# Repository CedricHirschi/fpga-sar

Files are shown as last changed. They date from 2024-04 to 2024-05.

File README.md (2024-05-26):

# FPGA-SAR

Material for the SAR ADC project in the **iCEBreaker FPGA For IoT Sensing Systems** FS2024 course.

## Project Description

Build a SAR ADC and a way to read its values.
- [x] Build analog part (See [hardware/](hardware/))
- [x] Develop SAR core (See [verilog/](verilog/))
- [x] Develop UART readout core (See [verilog/](verilog/))
- [ ] Optional: Evaluate speed and accuracy

## Project Structure

- [hardware/](hardware/): Contains the KiCad project for the analog part of the SAR ADC
- [verilog/](verilog/): Contains the Verilog code for the SAR ADC and UART readout core
- [gui.ipynb](gui.ipynb): Jupyter notebook for plotting the ADC values
- [activate.sh](activate.sh): Script to activate the virtual environment for development with APIO and Jupyter Notebook
- [presentation.pptx](presentation.pptx): Presentation slides for the project

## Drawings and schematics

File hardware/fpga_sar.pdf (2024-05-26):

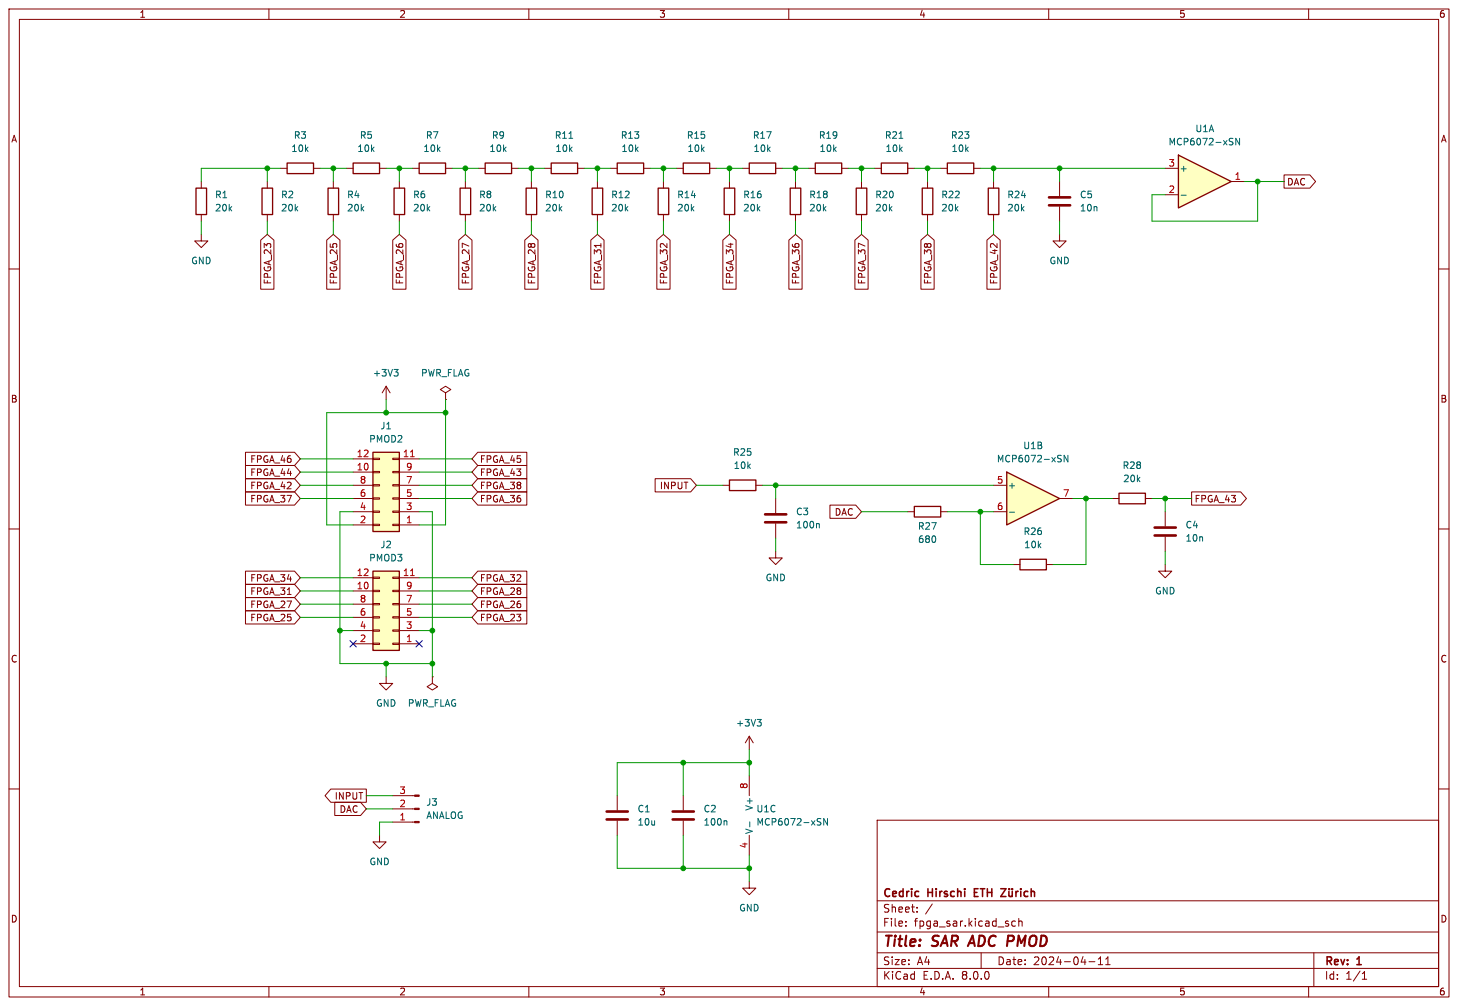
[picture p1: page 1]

Id: 1/1 Title: SAR ADC PMOD

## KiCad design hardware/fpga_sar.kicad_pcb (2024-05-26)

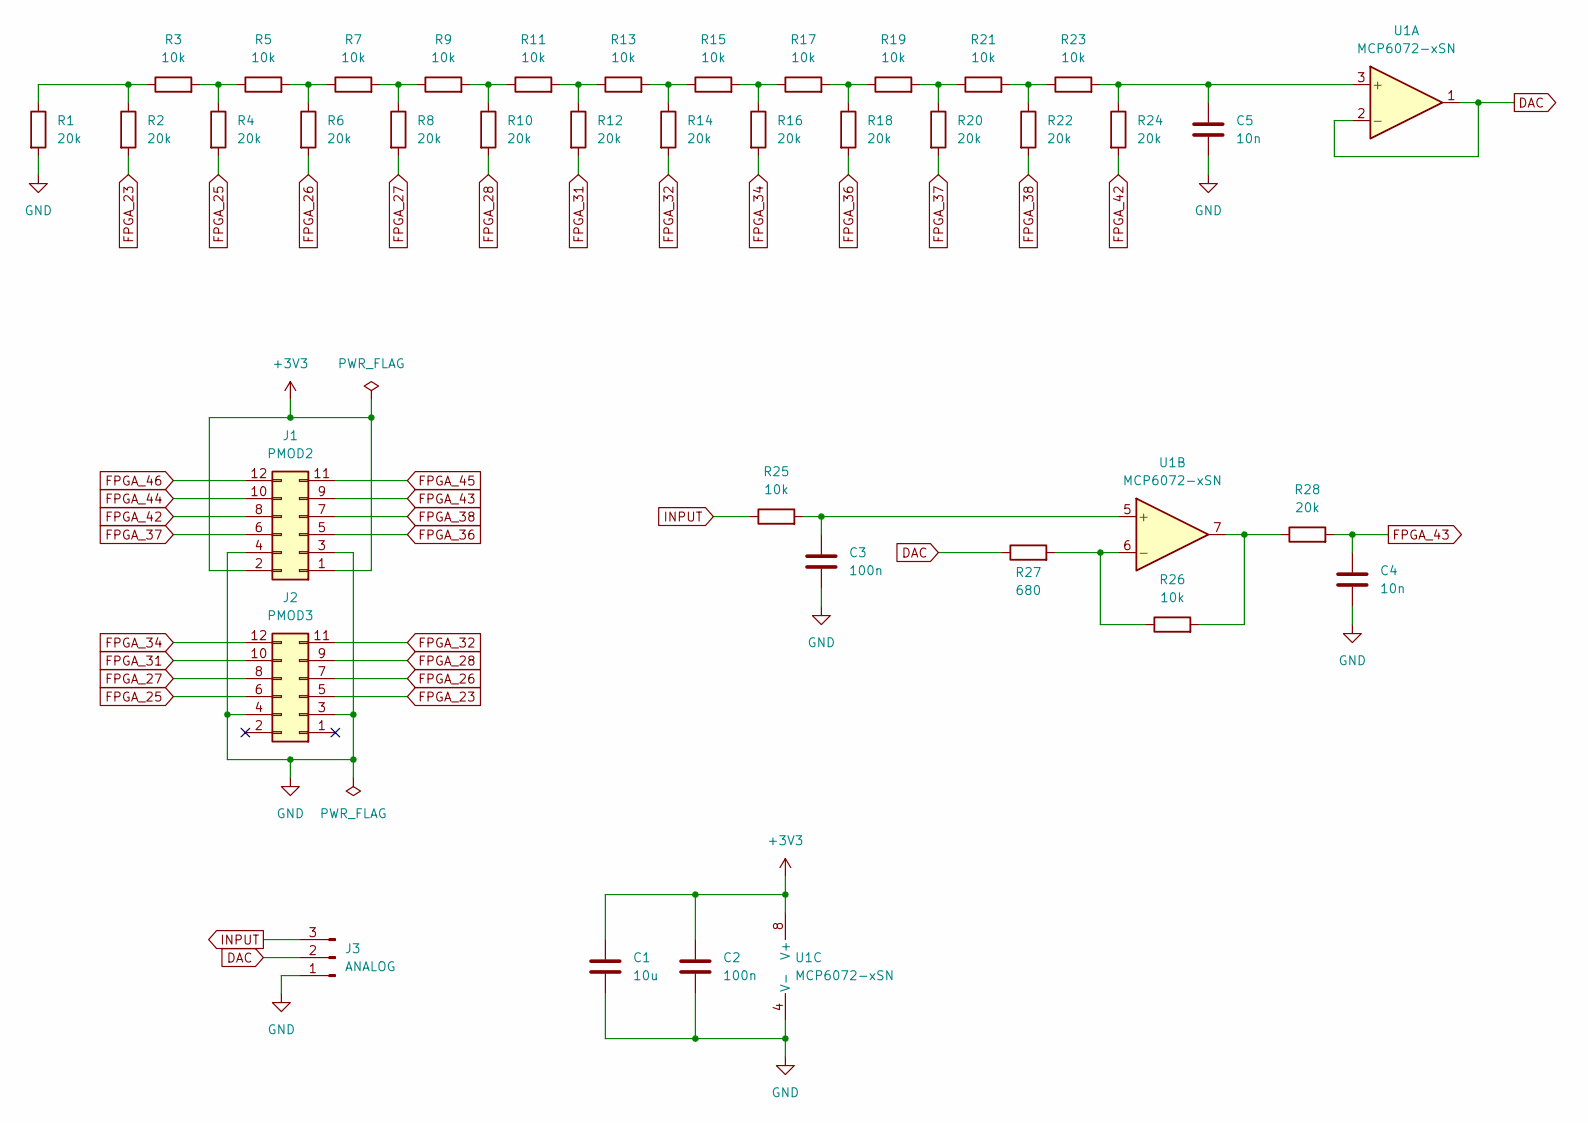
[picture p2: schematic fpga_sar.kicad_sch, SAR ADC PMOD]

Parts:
C1: 10u; C_0402_1005Metric
C2, C3: 100n; C_0402_1005Metric
C4, C5: 10n; C_0402_1005Metric
J1: PMOD2; PinHeader_2x06_P2.54mm_Horizontal
J2: PMOD3; PinHeader_2x06_P2.54mm_Horizontal
J3: ANALOG; PinHeader_1x03_P2.54mm_Vertical
R1, R2, R4, R6, R8, R10, R12, R14, R16, R18, R20, R22, R24, R28: 20k; R_0402_1005Metric
R3, R5, R7, R9, R11, R13, R15, R17, R19, R21, R23, R25, R26: 10k; R_0402_1005Metric
R27: 680; R_0402_1005Metric
U1: MCP6072-xSN; SOIC-8_3.9x4.9mm_P1.27mm

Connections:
+3V3: C1.1, C2.1, J1.1, J1.2, U1.8 (V+)
DAC: J3.2, R27.1, U1.1, U1.2 (-)
FPGA_23: J2.5, R2.2
FPGA_25: J2.6, R4.2
FPGA_26: J2.7, R6.2
FPGA_27: J2.8, R8.2
FPGA_28: J2.9, R10.2
FPGA_31: J2.10, R12.2
FPGA_32: J2.11, R14.2
FPGA_34: J2.12, R16.2
FPGA_36: J1.5, R18.2
FPGA_37: J1.6, R20.2
FPGA_38: J1.7, R22.2
FPGA_42: J1.8, R24.2
FPGA_43: C4.1, J1.9, R28.2
FPGA_44: J1.10
FPGA_45: J1.11
FPGA_46: J1.12
GND: C1.2, C2.2, C3.2, C4.2, C5.2, J1.3, J1.4, J2.3, J2.4, J3.1, R1.2, U1.4 (V-)
INPUT: J3.3, R25.1
unnamed: R1.1, R2.1, R3.1
unnamed: R3.2, R4.1, R5.1
unnamed: R5.2, R6.1, R7.1
unnamed: R7.2, R8.1, R9.1
unnamed: R9.2, R10.1, R11.1
unnamed: R11.2, R12.1, R13.1
unnamed: R13.2, R14.1, R15.1
unnamed: R15.2, R16.1, R17.1
unnamed: R17.2, R18.1, R19.1
unnamed: R19.2, R20.1, R21.1
unnamed: R21.2, R22.1, R23.1
unnamed: R26.2, R28.1, U1.7
unnamed: C5.1, R23.2, R24.1, U1.3 (+)
unnamed: C3.1, R25.2, U1.5 (+)
unnamed: R26.1, R27.2, U1.6 (-)

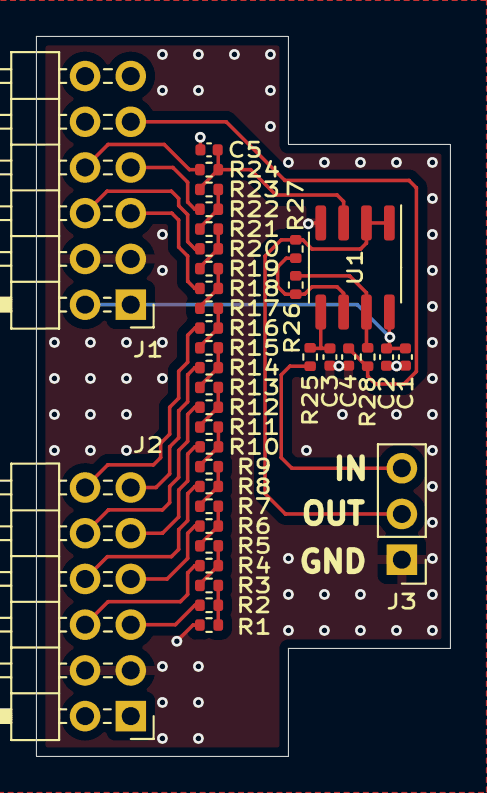
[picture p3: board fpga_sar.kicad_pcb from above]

Board: 2 copper layers, 23.0 x 40.0 mm, 37 parts (0 on the bottom side), 32 nets.

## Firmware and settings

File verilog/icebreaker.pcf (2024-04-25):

set_io start_o 11

set_io clk_i 35

set_io rst_ni 10

set_io uart_rx_i 6

set_io uart_tx_o 9

set_io comp_i 2

set_io dac_o[0] 31

set_io dac_o[1] 28

set_io dac_o[2] 34

set_io dac_o[3] 32

set_io dac_o[4] 38

set_io dac_o[5] 36

set_io dac_o[6] 43

set_io dac_o[7] 42

set_io dac_o[8] 45

set_io dac_o[9] 44

set_io dac_o[10] 47

set_io dac_o[11] 46

set_io rdy_o 37

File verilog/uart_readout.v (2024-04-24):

module uart_readout (
    input wire clk_i,
    input wire reset_ni,
    input wire en_i,
    input wire rx_i,
    output wire tx_o,
    input wire [11:0] adc_sample,           // ADC sample input
    input wire adc_sample_ready,            // ADC sample ready signal
    output reg adc_start_o                  // Output signal to start ADC conversion
);

wire tx_byte_ready_o;
wire [7:0] tx_byte_o;
assign tx_byte_ready_o = tx_byte_ready_q;
assign tx_byte_o = tx_byte_q;
wire tx_busy;

// UART TX instance
uart_tx u_uart_tx (
    .clk_i(clk_i),
    .reset_ni(reset_ni),
    .tx_data_i(tx_byte_o),
    .en_i(tx_byte_ready_o),
    .busy_o(tx_busy),
    .tx_o(tx_o)
);

// UART RX instance
wire [7:0] temp_rx_data;
wire temp_tx_ready;
uart_rx u_uart_rx (
    .clk_i(clk_i),
    .reset_ni(reset_ni),
    .rx_i(rx_i),
    .en_i(en_i),
    .rx_data_o(temp_rx_data),
    .rx_ready_o(temp_tx_ready)
);

// Buffer ADC sample
reg [11:0] adc_sample_buffer_q;
always @(posedge clk_i or negedge reset_ni) begin
    if (!reset_ni) begin
        adc_sample_buffer_q <= 12'b0;
    end else if (adc_sample_ready) begin
        adc_sample_buffer_q <= adc_sample;
    end
end

// TX state machine definitions
reg [2:0] uart_state;
localparam STATE_REST = 3'b000,
           STATE_WAIT_FOR_CONVERT = 3'b001,
           STATE_TX_SAMPLE = 3'b010,
           STATE_WAIT = 3'b011,
           STATE_CR = 3'b100,
           STATE_WAIT_CR = 3'b101,
           STATE_LF = 3'b110,
           STATE_WAIT_LF = 3'b111;

reg tx_byte_ready_q;
reg [7:0] tx_byte_q;
reg [11:0] adc_shift_buffer_q;
reg [4:0] bit_count_q;
reg [15:0] delay_counter_q;
reg temp_tx_ready_old;

always @(posedge clk_i or negedge reset_ni) begin
    if (!reset_ni) begin
        uart_state <= STATE_REST;
        temp_tx_ready_old <= 1'b0;
        tx_byte_ready_q <= 1'b0;
        tx_byte_q <= 8'b0;
        adc_shift_buffer_q <= 12'b0;
        bit_count_q <= 5'b0;
        delay_counter_q <= 16'b0;
        adc_start_o <= 1'b0;  // Default state not triggering ADC
    end else begin
        temp_tx_ready_old <= temp_tx_ready;
        case (uart_state)
            STATE_REST: begin
                if (~temp_tx_ready_old & temp_tx_ready & (temp_rx_data == 8'h73)) begin
                    adc_start_o <= 1'b1; // Start ADC conversion
                    uart_state <= STATE_WAIT_FOR_CONVERT;
                end else begin
                    adc_start_o <= 1'b0; // Ensure ADC is not repeatedly triggered
                    tx_byte_q <= temp_rx_data;
                    tx_byte_ready_q <= temp_tx_ready;
                end
            end
            STATE_WAIT_FOR_CONVERT: begin
                if (adc_sample_ready) begin
                    adc_shift_buffer_q <= adc_sample_buffer_q;
                    uart_state <= STATE_TX_SAMPLE;
                end
            end
            STATE_TX_SAMPLE: begin
				adc_start_o <= 1'b0; // Ensure ADC is not repeatedly triggered
                if (bit_count_q < 12) begin
                    tx_byte_q <= (adc_shift_buffer_q[11] ? 8'h31 : 8'h30); // Convert binary to ASCII '0' or '1'
                    tx_byte_ready_q <= 1'b1;
                    adc_shift_buffer_q <= adc_shift_buffer_q << 1;
                    bit_count_q <= bit_count_q + 1;
                    uart_state <= STATE_WAIT;
                end else begin
                    bit_count_q <= 5'b0;
                    uart_state <= STATE_CR;
                end
            end
            STATE_WAIT: begin
                tx_byte_ready_q <= 1'b0;
                if (!tx_busy && delay_counter_q < 16'h013F) begin
                    delay_counter_q <= delay_counter_q + 1;
                end else if (!tx_busy) begin
                    delay_counter_q <= 16'b0;
                    uart_state <= STATE_TX_SAMPLE;
                end
            end
            STATE_CR: begin
                tx_byte_q <= 8'h0D;  // Carriage return
                tx_byte_ready_q <= 1'b1;
                uart_state <= STATE_WAIT_CR;
            end
            STATE_WAIT_CR,
            STATE_WAIT_LF: begin
                tx_byte_ready_q <= 1'b0;
                if (!tx_busy && delay_counter_q < 16'h013F) begin
                    delay_counter_q <= delay_counter_q + 1;
                end else if (!tx_busy) begin
                    delay_counter_q <= 16'b0;
                    uart_state <= (uart_state == STATE_WAIT_CR ? STATE_LF : STATE_REST);
                end
            end
            STATE_LF: begin
                tx_byte_q <= 8'h0A;  // Line feed
                tx_byte_ready_q <= 1'b1;
                uart_state <= STATE_WAIT_LF;
            end
            default: uart_state <= STATE_REST;
        endcase
    end
end

endmodule

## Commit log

2024-04-24 Add UART readout
    Send 's' via UART 115200, 8 bits, 1 stop, no parity
2024-04-25 Fix pinout for breakout
    [icebreaker.pcf]
2024-05-26 Preparation for presentation
    [fpga_sar.kicad_pcb, fpga_sar.kicad_sch]
